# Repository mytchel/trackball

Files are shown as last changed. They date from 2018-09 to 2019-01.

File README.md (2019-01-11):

# Mytchel's Trackball

A trackball 

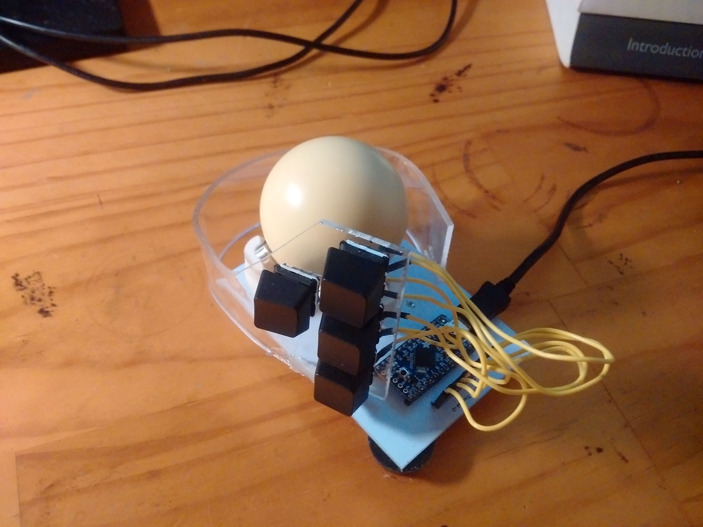
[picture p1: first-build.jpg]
trackball


Parts:
- a 52.5mm snooker ball
- Three [8mm bearing ball rollers](https://www.aliexpress.com/item/Miniature-8mm-robot-bearing-steel-ball-roller-KSM-8-Swivel-Round-Mini-Ball-Caster-Press-Mount/32838128238.html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)
- ADNS 9800 laser mouse sensor.
- Adafruit ItsyBitsy 32u4 3V
- Some capacitors and transistors for the board.
- Four Cherry MX keyboard switches as buttons.
- A 3D printed cradle 
- And the PCB.

The schematics for the PCB are under [board/](board/) and were created in GEDA.
The cradle was designed using OpenSCAD and is at [cradle/mouse.scad](cradle/mouse.scad).
I think [cradle/mouse3.stl](cradle/mouse3.stl) is the file I had printed.
And the code is under [src](src) and is based off the 
[mouse example for the Teensy](https://www.pjrc.com/teensy/usb_mouse.html).

Under [case/](case) is the beginnings of the design for a case, though I think
the PCB needs some changes before this progresses much. Currently the case is
a piece of 3mm acrylic with cutouts for the switches, then heated and bent into
shape. In future I will move away from the keyboard keys to micro switches. Keys
are not meant to be used like buttons on a mouse and pretending they are will
cause pain. It does for me at least.

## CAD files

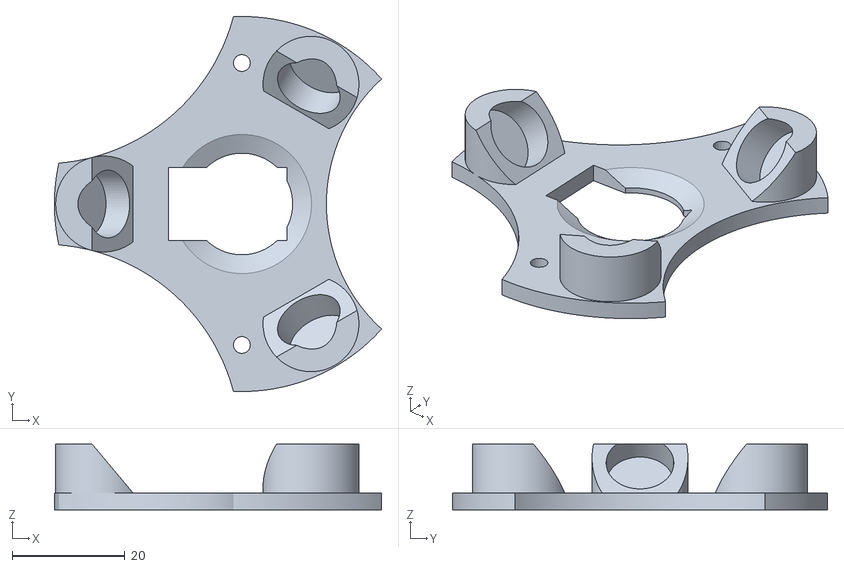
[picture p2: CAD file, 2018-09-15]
cradle/mouse2.stl
58.0 x 66.5 x 11.7

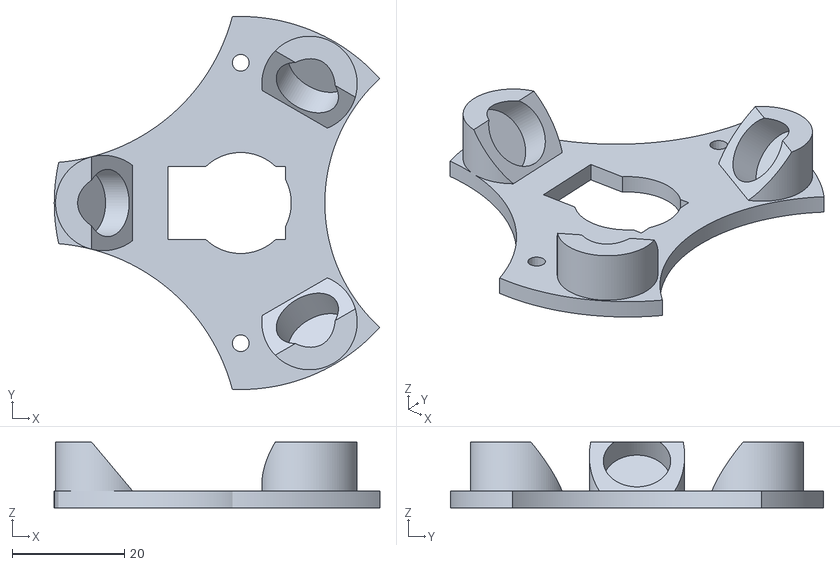
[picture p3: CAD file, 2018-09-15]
cradle/mouse.stl
58.0 x 66.5 x 11.7

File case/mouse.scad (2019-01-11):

$fa = 1;
$fs = 0.5;

module bearing () {
    translate([0, 0, 10.5-4])
    sphere(d = 8);
    cylinder(h = 8.7, d = 12);
}

module bearing_holder() {
    rotate([0, 50, 0])
    difference() {
        translate([0, 0, -32])
        rotate([0, -50, 0])
        translate([0, 0, -7])
        cylinder(h = 11, d = 17);
            
        translate([-5, -10, -26-5])
        cube([20, 20, 20]);
    }
}

module ball_and_bearings() {	
    translate([0, 0, 28.25]) {
        sphere(d = 52.5);

        rotate([0, 50, 0])
        translate([0, 0, -26])
        translate([0, 0, -10.5])
        bearing();
        rotate([0, 50, 120])
        translate([0, 0, -26])
        translate([0, 0, -10.5])
        bearing();
        rotate([0, 50, 240])
        translate([0, 0, -26])
        translate([0, 0, -10.5])
        bearing();
    }
}

module cradle() {
	difference() {
		union() {
			translate([0, 0, 28.25]) {
				rotate([0, 0, 0])
					bearing_holder();

				rotate([0, 0, 120])
					bearing_holder();

				rotate([0, 0, 240])
					bearing_holder();
			}

			difference() {
				cylinder(h = 3, d = 66.5);

				translate([-21+8, -13/2, -1])
					cube([21, 13, 5]);

				translate([0, 0, -1])
					cylinder(h = 2.1, d = 18);
				translate([0, 0, 1])
					cylinder(h = 3, d1 = 18, d2 = 28);

				translate([0, 25, -1])
					cylinder(h = 7, d = 3);

				translate([0, -25, -1])
					cylinder(h = 7, d = 3);


				rotate([0, 0, 230])
					translate([55, 0, -1])
					cylinder(h = 7, d = 70);

				rotate([0, 0, 130])
					translate([55, 0, -1])
					cylinder(h = 7, d = 70);

				translate([45, 0, -1])
					cylinder(h = 7, d = 60);
			}
		}

		translate([0, 0, 28.25]) {
			rotate([0, 50, 0])
				translate([0, 0, -26])
				translate([0, 0, -10.5])
				bearing();
			rotate([0, 50, 120])
				translate([0, 0, -26])
				translate([0, 0, -10.5])
				bearing();
			rotate([0, 50, 240])
				translate([0, 0, -26])
				translate([0, 0, -10.5])
				bearing();
		}
	}
}

module board() {
	translate([-(100-25), -35, -5]) {
		cube([100, 70, 2]);

		/* micro */
		translate([13.8, 17, 2])
			cube([15+1.3*2, 31+1.3*2, 15]);

		/* button header */
		translate([6.6, 24.3, 2])
			cube([3.6, 20, 15]);
	}
}

module case() {
	translate([-50, 25, 2]) {
		rotate([100, 0, 20]) {
			difference() {
				cube([3 * 2 + 19 * 2 + 15, 3 * 2 + 19 * 3, 5]);

				translate([3 + 3, 3 + 3, -1]) {
					cube([14, 14, 3]);
					translate([-1, -1, 2.5])
						cube([16, 16, 8]);
				}

				translate([3 + 3, 3 + 3 + 19, -1]) {
					cube([14, 14, 3]);
					translate([-1, -1, 2.5])
						cube([16, 16, 8]);
				}

				translate([3 + 3 + 19, 3 + 3 + 19, -1]) {
					cube([14, 14, 3]);
					translate([-1, -1, 2.5])
						cube([16, 16, 8]);
				}

				translate([3 + 3, 3 + 3 + 19 * 2, -1]) {
					cube([14, 14, 3]);
					translate([-1, -1, 2.5])
						cube([16, 16, 8]);
				}

				translate([3 + 19, 3 * 2 + 19 * 3, -1])	
					rotate([0, 0, -50])
					difference() {
						cube([80, 40, 8]);
					}
			}
		}
	}

	translate([10, 10, -5]) 
		cylinder(h = 30, r = 30);
}

translate([0, 0, 5]) {
	cradle();
	ball_and_bearings();
	board();
}

case();

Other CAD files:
cradle/mouse.scad

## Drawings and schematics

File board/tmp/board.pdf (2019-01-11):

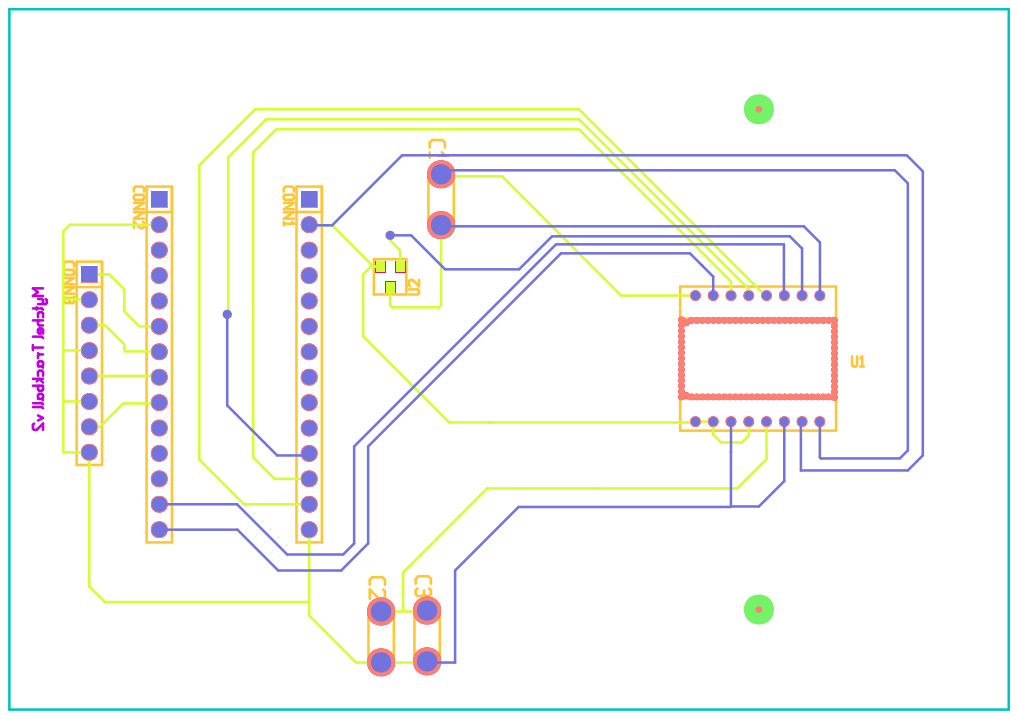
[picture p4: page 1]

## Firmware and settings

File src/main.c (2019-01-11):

#include <avr/io.h>
#include <avr/pgmspace.h>
#include <util/delay.h>
#include <stdarg.h>
#include <stdio.h>

#include "usb_mouse.h"
#include "spi.h"

#include "adns.h"

int main(void)
{
	int light, light_delay;
	int8_t dx, dy, sx, sy;
	int8_t l, m, r, s;

	DDRD |= (1<<2);
	DDRC |= (1<<7);

	/* Enable pull ups on buttons */
	PORTB |= (1 << 7) | (1 << 6) | (1 << 5);
	PORTE |= (1 << 6);

	if (!adns_init()) {
		while (1)
			;
	}

	usb_init();
	while (!usb_configured()) /* wait */ ;

	_delay_ms(500);

	light = 0;
	light_delay = 0;
	sx = 0;
	sy = 0;
	
	while (1) {
		l = 0;
		m = 0;
		r = 0;
		s = 0;
		for (int i = 0; i < 100; i++) {
			l += !((PINB >> 7) & 1);
			m += !((PINB >> 6) & 1);
			r += !((PINB >> 5) & 1);
			s += !((PINE >> 6) & 1);

			if (i >= light) {
				PORTC &= ~(1<<7);
			} else {
				PORTC |= (1<<7);
			}
			_delay_us(10);
		}

		if (light > 0) {
			if (light_delay++ == 10) {
				light--;
				light_delay = 0;
			}
		}

		l = l > 80;
		m = m > 80;
		r = r > 80;
		s = s > 80;

		usb_mouse_buttons(l, m, r);

		if (adns_motion(&dx, &dy)) {
			light = 50;

			if (s) {
				sx += dx;
				sy -= dy;
				dx = 0;
				dy = 0;

#define SCROLL_LIM 15

				if (sx < -SCROLL_LIM || SCROLL_LIM < sx) {
					dx = sx / SCROLL_LIM;//sx > 0 ? 1 : -1;
					sx = 0;
				}

				if (sy < -SCROLL_LIM || SCROLL_LIM < sy) {
					dy = sy / SCROLL_LIM;//sy > 0 ? 1 : -1;
					sy = 0;
				}

				usb_mouse_move(0, 0, dx, dy);
			} else {
				usb_mouse_move(dx, dy, 0, 0);
				sx = 0;
				sy = 0;
			}
		}
	}
}

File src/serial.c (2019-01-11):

/* Simple example for Teensy USB Development Board
 * http://www.pjrc.com/teensy/
 * Copyright (c) 2008 PJRC.COM, LLC
 * 
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
 * THE SOFTWARE IS PROVIDED "AS IS", WITHOUT WARRANTY OF ANY KIND, EXPRESS OR
 * IMPLIED, INCLUDING BUT NOT LIMITED TO THE WARRANTIES OF MERCHANTABILITY,
 * FITNESS FOR A PARTICULAR PURPOSE AND NONINFRINGEMENT. IN NO EVENT SHALL THE
 * AUTHORS OR COPYRIGHT HOLDERS BE LIABLE FOR ANY CLAIM, DAMAGES OR OTHER
 * LIABILITY, WHETHER IN AN ACTION OF CONTRACT, TORT OR OTHERWISE, ARISING FROM,
 * OUT OF OR IN CONNECTION WITH THE SOFTWARE OR THE USE OR OTHER DEALINGS IN
 * THE SOFTWARE.
 */

#include <avr/io.h>
#include <avr/pgmspace.h>
#include <stdint.h>
#include <stdio.h>
#include <string.h>
#include <util/delay.h>
#include "usb_serial.h"

#include "../mouse/spi.h"
#include "../mouse/adns.h"

void send_str(const char *s);
uint8_t recv_str(char *buf, uint8_t size);
void parse_and_execute_command(const char *buf, uint8_t num);

int main(void)
{
	char buf[32];
	uint8_t n;

	PORTB |= (1<<7)|(1<<6)|(1<<5);
	PORTE |= (1<<6);

	adns_init();

	usb_init();
	while (!usb_configured()) /* wait */ ;
	_delay_ms(1000);

	while (1) {
		while (!(usb_serial_get_control() & USB_SERIAL_DTR)) /* wait */ ;

		// discard anything that was received prior.  Sometimes the
		// operating system or other software will send a modem
		// "AT command", which can still be buffered.
		usb_serial_flush_input();

		send_str(PSTR("\r\nTeensy USB Serial.\r\n"));

		// and then listen for commands and process them
		while (1) {
			/*
			send_str(PSTR("> "));
			n = recv_str(buf, sizeof(buf));
			if (n == 255) break;
			send_str(PSTR("\r\n"));
			*/
			parse_and_execute_command(buf, n);
		}
	}
}

// Send a string to the USB serial port.  The string must be in
// flash memory, using PSTR
//
void send_str(const char *s)
{
	char c;
	while (1) {
		c = pgm_read_byte(s++);
		if (!c) break;
		usb_serial_putchar(c);
	}
}

// Receive a string from the USB serial port.  The string is stored
// in the buffer and this function will not exceed the buffer size.
// A carriage return or newline completes the string, and is not
// stored into the buffer.
// The return value is the number of characters received, or 255 if
// the virtual serial connection was closed while waiting.
//
uint8_t recv_str(char *buf, uint8_t size)
{
	int16_t r;
	uint8_t count=0;

	while (count < size) {
		r = usb_serial_getchar();
		if (r != -1) {
			if (r == '\r' || r == '\n') return count;
			if (r >= ' ' && r <= '~') {
				*buf++ = r;
				usb_serial_putchar(r);
				count++;
			}
		} else {
			if (!usb_configured() ||
			  !(usb_serial_get_control() & USB_SERIAL_DTR)) {
				// user no longer connected
				return 255;
			}
			// just a normal timeout, keep waiting
		}
	}
	return count;
}

// parse a user command and execute it, or print an error message
//
void parse_and_execute_command(const char *buf, uint8_t num)
{
	char c[128];
/*
	sprintf(s, "product id: 0x%x\r\n", spi_read(0x0));
	usb_serial_write((uint8_t *) s, strlen(s));
	sprintf(s, "revision id: 0x%x\r\n", spi_read(0x1));
	usb_serial_write((uint8_t *) s, strlen(s));

	sprintf(s, "srom id: 0x%x\r\n", spi_read(0x2a));
	usb_serial_write((uint8_t *) s, strlen(s));

	sprintf(s, "squall: 0x%x\r\n", ((uint16_t) spi_read(0x07)) << 2);
	usb_serial_write((uint8_t *) s, strlen(s));

	sprintf(s, "lift dectection: 0x%x\r\n", spi_read(0x2e));
	usb_serial_write((uint8_t *) s, strlen(s));

	sprintf(s, "c2: 0x%x\r\n", spi_read(0x10));
	usb_serial_write((uint8_t *) s, strlen(s));

	sprintf(s, "rpt: 0x%x\r\n", spi_read(0x10) & (1<<2));
	usb_serial_write((uint8_t *) s, strlen(s));

	sprintf(s, "dx res: 0x%x\r\n", spi_read(0x0f));
	usb_serial_write((uint8_t *) s, strlen(s));

	sprintf(s, "dy res: 0x%x\r\n", spi_read(0x2f));
	usb_serial_write((uint8_t *) s, strlen(s));

	sprintf(s, "snap: 0x%x\r\n", spi_read(0x42));
	usb_serial_write((uint8_t *) s, strlen(s));

*/

	int8_t dx, dy;
	bool mot = adns_motion(&dx, &dy);

	int l, m, r, s;

	l = !((PINB>>7)&1);
	m = !((PINB>>6)&1);
	r = !((PINB>>5)&1);
	s = !((PINE>>6)&1);

	sprintf(c, "%i %i %i %i : %i : %5i,%5i\r\n", l, m, r, s, mot, dx, dy);
	usb_serial_write((uint8_t *) c, strlen(c));
	_delay_ms(10);
}

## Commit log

2018-09-15 Restructure, make cradle, start on pcb.
    [board.sch, mouse.scad, mouse.stl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]
2018-09-15 Try adding footprints. Not working on laptop.
    [adns-5030-1.sch, board.sch]
2018-09-15 Add cherry footprint.
    [board.sch]
2018-09-15 sch2pcb seems to work.
    [board.sch]
2018-09-15 Need to make a proper footprint for adns5030
    [board.sch]
2018-09-16 Need to reduce the size.
    [board.sch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]
2018-09-17 Using mouse bites for the cutout for now.
    [board.bottom.gbr, board.bottommask.gbr, board.bottompaste.gbr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]
2018-11-19 Update for adns9800 which has not been tested.
    [board.sch]
2018-12-15 Cleanup old files.
    [board.bottom.gbr, board.bottommask.gbr, board.bottompaste.gbr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]
2018-12-22 Add debouncing for buttons.
2018-12-23 Revert to 8 bit coords as windows doesn't support 16.
    [adns.c, main.c]
2019-01-11 Cleanup the tree.
    [mouse.scad]
